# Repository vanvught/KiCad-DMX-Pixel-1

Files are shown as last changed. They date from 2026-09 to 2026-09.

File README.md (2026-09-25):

# KiCad DMX/RDM and Pixel 1-port 

Firmware 

- [https://github.com/vanvught/GD32F103RC-DMX512-RDM](https://github.com/vanvught/GD32F103RC-DMX512-RDM)
- [https://github.com/vanvught/GD32F107RC-DMX512-RDM](https://github.com/vanvught/GD32F107RC-DMX512-RDM)
- [https://github.com/vanvught/GD32F303RC-DMX512-RDM](https://github.com/vanvught/GD32F303RC-DMX512-RDM)

More information [https://www.gd32-dmx.org/pixel.html](https://www.gd32-dmx.org/pixel.html)

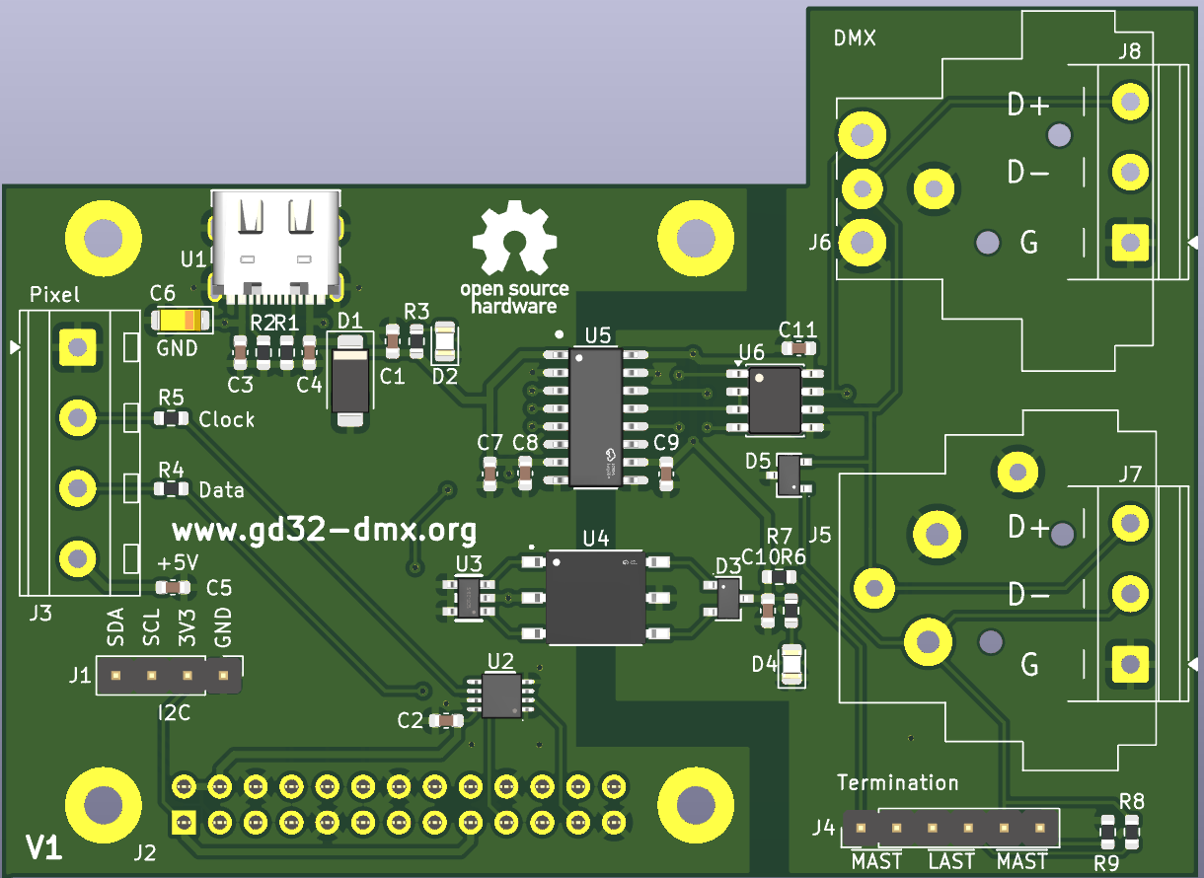
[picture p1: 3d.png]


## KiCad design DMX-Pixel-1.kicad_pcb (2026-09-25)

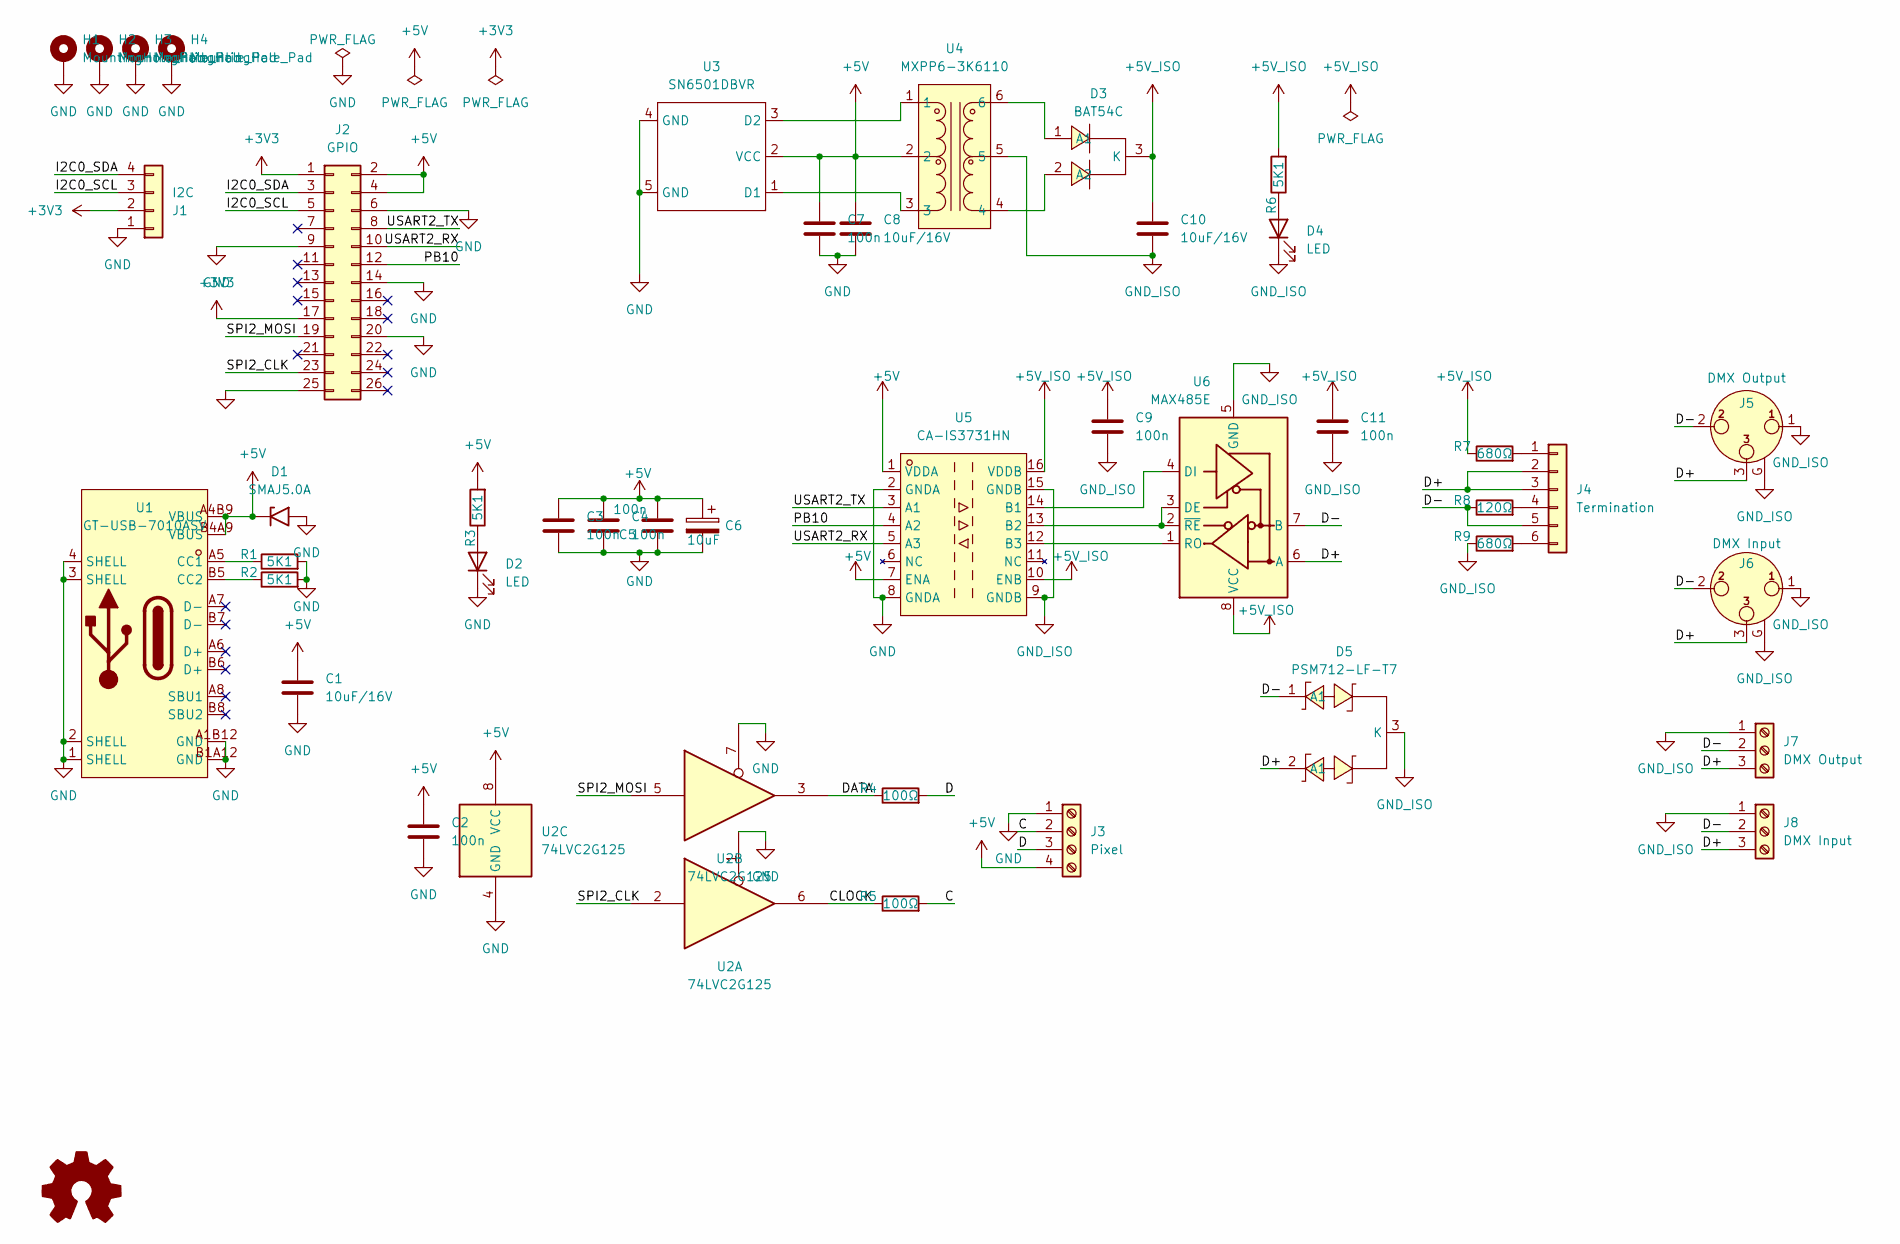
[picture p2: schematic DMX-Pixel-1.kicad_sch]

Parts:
C1, C8, C10: 10uF/16V; C_0603_1608Metric; LCSC Part C19702
C2, C3, C4, C5, C7, C9, C11: 100n; C_0603_1608Metric; LCSC Part C14663
C6: 10uF; CP_EIA-3216-18_Kemet-A; LCSC Part C7171
D1: SMAJ5.0A; D_SMA; LCSC Part C113952
D2, D4: LED; LED_0805_2012Metric; LCSC Part C2297
D3: BAT54C; SOT-23-3_L2.9-W1.6-P1.90-LS2.8-BR; MPN BAT54C; LCSC Part C2135
D5: PSM712-LF-T7; SOT-23-3_L3.0-W1.7-P0.95-LS2.9-BR; MPN PSM712-LF-T7; LCSC Part C32677
H1, H2, H3, H4: MountingHole_Pad; MountingHole_2.7mm_M2.5_Pad
J1: I2C; PinHeader_1x04_P2.54mm_Vertical
J2: GPIO; PinSocket_2x13_P2.54mm_Vertical
J3: Pixel; TerminalBlock_MetzConnect_Type094_RT03504HBLU_1x04_P5.00mm_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
J4: Termination; PinHeader_1x06_P2.54mm_Vertical
J5: DMX Output; Jack_XLR_Neutrik_NC3FAH2_Horizontal
J6: DMX Input; Jack_XLR_Neutrik_NC3MAH_Horizontal
J7: DMX Output; TerminalBlock_MetzConnect_Type094_RT03503HBLU_1x03_P5.00mm_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
J8: DMX Input; TerminalBlock_MetzConnect_Type094_RT03503HBLU_1x03_P5.00mm_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
R1, R2, R3, R6: 5K1; R_0603_1608Metric; LCSC Part C23186
R4, R5: 100Ω; R_0603_1608Metric; LCSC Part C22775
R7, R9: 680Ω; R_0603_1608Metric; LCSC Part C23228
R8: 120Ω; R_0603_1608Metric; LCSC Part C22787
SYM1: Logo_Open_Hardware_Small; OSHW-Logo_7.5x8mm_SilkScreen
U1: GT-USB-7010ASV; USB-C-SMD_G-SWITCH_GT-USB-7010ASV; MPN GT-USB-7010ASV; LCSC Part C2988369
U2: 74LVC2G125; SM8_L3.2-W2.9-P0.65-LS4.3-BR; LCSC Part C206035
U3: SN6501DBVR; SOT-23-5_L3.0-W1.7-P0.95-LS2.8-BR; MPN SN6501DBVR; LCSC Part C49451
U4: MXPP6-3K6110; XFMR-SMD_L7.1-W6.6-P2.54_LT31-120; MPN MXPP6-3K6110; LCSC Part C19943838
U5: CA-IS3731HN; SOIC-16_L9.9-W3.9-P1.27-LS6.0-BL; MPN CA-IS3731HN; LCSC Part C428880
U6: MAX485E; SOIC-8_3.9x4.9mm_P1.27mm; LCSC Part C23492

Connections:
+3V3: J1.2, J2.1, J2.17
+5V: C1.1, C2.1, C3.1, C4.1, C5.2, C6.1, C7.1, C8.1, D1.1 (A1), J2.2, J2.4, J3.4, R3.2, U1.A4B9 (VBUS), U1.B4A9 (VBUS), U2.8 (VCC), U3.2 (VCC), U4.2, U5.1 (VDDA), U5.7 (ENA)
+5V_ISO: C9.1, C10.1, C11.1, D3.3 (K), R6.2, R7.1, U5.10 (ENB), U5.16 (VDDB), U6.8 (VCC)
/C: J3.2, R5.2
/CLOCK: R5.1, U2.6
/D: J3.3, R4.2
/D+: D5.2 (A1), J4.2, J4.3, J5.3, J6.3, J7.3, J8.3, U6.6 (A)
/D-: D5.1 (A1), J4.5, J5.2, J6.2, J7.2, J8.2, R8.1, U6.7 (B)
/DATA: R4.1, U2.3
/I2C0_SCL: J1.3, J2.5
/I2C0_SDA: J1.4, J2.3
/PB10: J2.12, U5.4 (A2)
/SPI2_CLK: J2.23, U2.2
/SPI2_MOSI: J2.19, U2.5
/USART2_RX: J2.10, U5.5 (A3)
/USART2_TX: J2.8, U5.3 (A1)
GND: C1.2, C2.2, C3.2, C4.2, C5.1, C6.2, C7.2, C8.2, D1.2 (A2), D2.1 (K), H1.1 (1_1), H2.1 (1_1), H3.1 (1_1), H4.1 (1_1), J1.1, J2.6, J2.9, J2.14, J2.20, J2.25, J3.1, R1.2, R2.2, U1.1 (SHELL), U1.2 (SHELL), U1.3 (SHELL), U1.4 (SHELL), U1.A1B12 (GND), U1.B1A12 (GND), U2.1, U2.4 (GND), U2.7, U3.4 (GND), U3.5 (GND), U5.2 (GNDA), U5.8 (GNDA)
GND_ISO: C9.2, C10.2, C11.2, D4.1 (K), D5.3 (K), J5.1, J5.G, J6.1, J6.G, J7.1, J8.1, R9.1, U4.5, U5.9 (GNDB), U5.15 (GNDB), U6.5 (GND)
unnamed: D2.2 (A), R3.1
unnamed: D3.1 (A1), U4.6
unnamed: D3.2 (A2), U4.4
unnamed: D4.2 (A), R6.1
unnamed: J4.1, R7.2
unnamed: J4.4, R8.2
unnamed: J4.6, R9.2
unnamed: R1.1, U1.A5 (CC1)
unnamed: R2.1, U1.B5 (CC2)
unnamed: U3.1 (D1), U4.3
unnamed: U3.3 (D2), U4.1
unnamed: U5.14 (B1), U6.4 (DI)
unnamed: U5.13 (B2), U6.2 (~RE), U6.3 (DE)
unnamed: U5.12 (B3), U6.1 (RO)

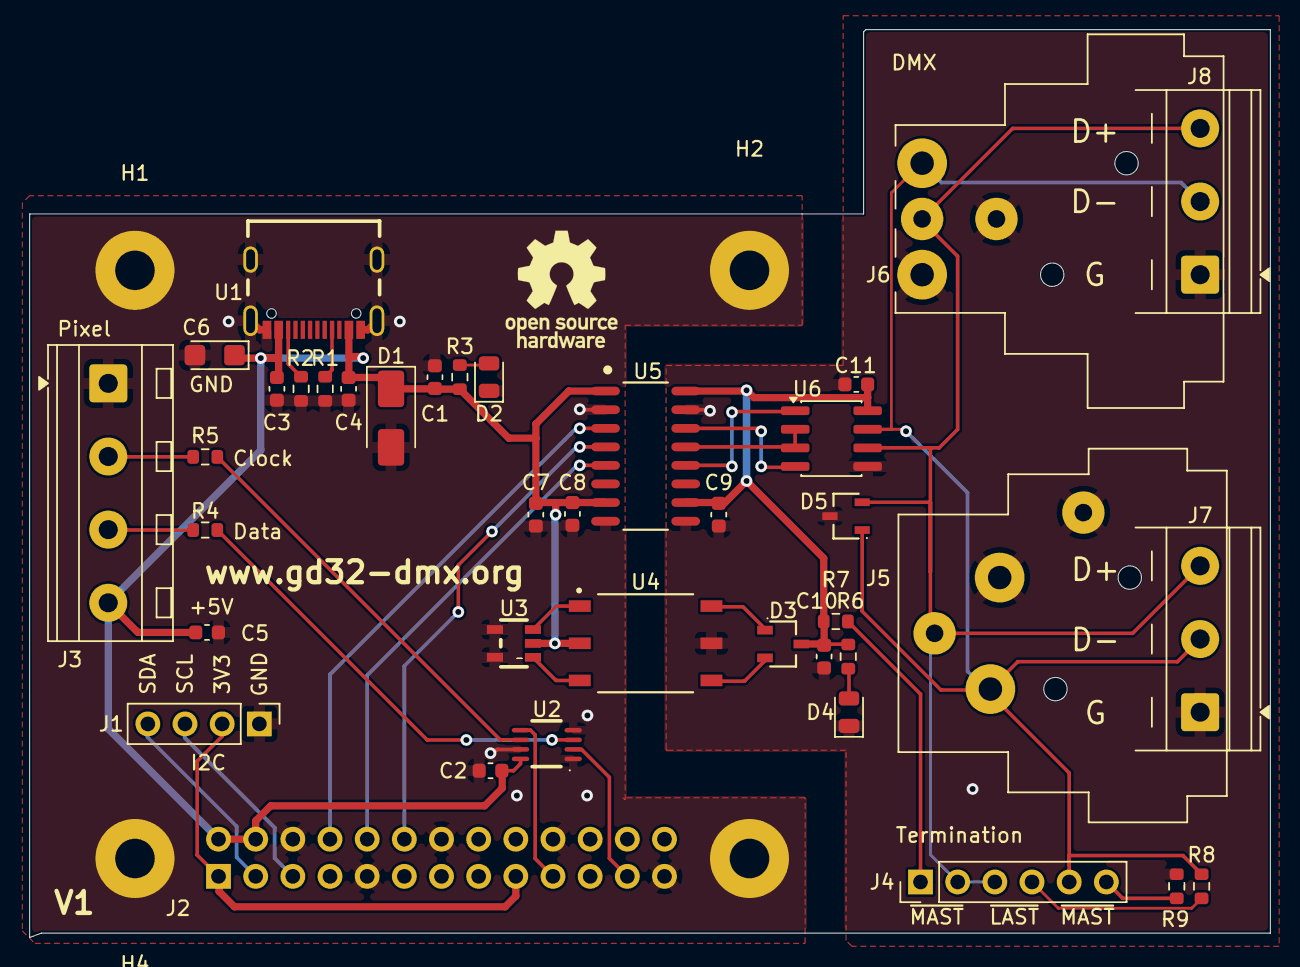
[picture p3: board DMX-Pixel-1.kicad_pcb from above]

Board: 2 copper layers, 84.8 x 62.0 mm, 44 parts (1 on the bottom side), 32 nets.
